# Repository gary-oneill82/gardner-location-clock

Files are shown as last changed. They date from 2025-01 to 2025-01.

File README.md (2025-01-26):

# The Gardner (Weasley) Family Clock

Happy Birthday Paul and welcome to your own version of the Weasley family clock!  The mechanism is mostly 3D printed and the STL files are available in the repository should anything break or wear out.

## First Start

When you first plug the clock in it will run a demonstration mode to move the hands to various locations before returning to home.  The Clock will present an Access Point with an SSID of "Location-Clock", I have given Laura the password.  Connect to the AP and connect to your own Wifi, the clock will now be available at http://weasley-clock.local, Laura has the Log in details for this also.

## Basic Controls

The Control software has been written in [ESPHome](https://esphome.io/) and provides a Web Server with [REST API](https://esphome.io/web-api/#api-rest).  Both hands are controlled by "Select" entities on the clock and the current state can be returned with a GET request to `http://weasley-clock.local/select/laura_location?detail=all` or `http://weasley-clock.local/select/paul_location?detail=all` this will return the following JSON Payload:
```
{
  "id":"select-laura_location",
  "name":"Laura Location",
  "icon":"",
  "entity_category":0,
  "value":"Home",
  "state":"Home",
  "option":["Home","Hogwarts","Work","Hogsmede","Quiddich","Holiday","Crieff Hydro","In Transit","Mortal Peril","Lost"],
  "sorting_weight":2,
  "sorting_group":"Controls"
}
```
To Control the hands simply send a POST request, for example `http://weasley-clock.local/select/laura_location/set?option=Hogwarts`

## Automation

If you want the clock to update locations automatically you will need to work out the best way to do this for the two of you but there are a few options:

1. We run our Smart house on [Home Assistant](https://www.home-assistant.io/) which integrates directly with ESPHome devices, has iOS and Android apps that can report location back to the server and can be programmed with automations, this is pretty much an all in one solution.
2. OwnTracks is open source and requires a phone app and server at home (can be a Rapberry Pi) as used in [this project](https://github.com/WhereslyClock/MyWhereslyClock), you then just have to work out the bridge to send the POST request to the Clock
3. Any other loction tracking service with an API should work as well so long as you write a middle-man programme to report to the clock where you each are!

## Calibration

While the hands are glued to the shafts there may still be some drift over time, if the hands stop consistently pointing to the correct location I have built in a Calibration option.  To access this go to [http://weasley-clock.local](http://weasley-clock.local) while connected to your home network and switch the "Access Calibration" switch (you will need to refresh the web page after changing the switch).  Once this is done you should see some additional options:



You now need to do the following:
1. Select the person + location that needs calibration from the top
2. Refresh the page to force the control location to update
3. Slowly move the control until the hand is in the correct location (you can click the slider and use the arrow keys on the keyboard to move one small step at a time)
4. Press the Save Calibration button for the corresponding hand - this will update the Location with the current hand position

## Administration

If needed you can upload an updated firmware for the clock by selecting "Allow OTA updates" and refreshing the page.  The Firmware files are in the Firmware section of the repository along with the ESPHome YAML file should you wish to make any changes yourself.  If needed you can reflash the firmware direct from a computer by unscewing the clock face and gently unplugging the USB extension cable to the control board.  You can then plug the ESP-32S board direct into the computer to be presented with a serial port, you will need to hold the small "BOOT" button on the board and press the "EN" button to enable the bootloader mode.  When putting things back together I would suggeest plugging into the breakout board to avoid the servos pulling current through the controller.

IMG_20250125_200230~2

## Hardware

> [!IMPORTANT]
> The Hands are superglued to the shafts so if you need to take the clock apart let me know and I'll talk you through it.

+ Controller: ESP-32S Dev board
+ Hand Servos: [Tower Pro MG90S](https://towerpro.com.tw/product/mg90s-3/)
+ Gears and hands: 3D printed in PLA+
+ Fasteners: M2 grub screws (0.9mm Hex bit) for Gears, M5 Screws for main body.

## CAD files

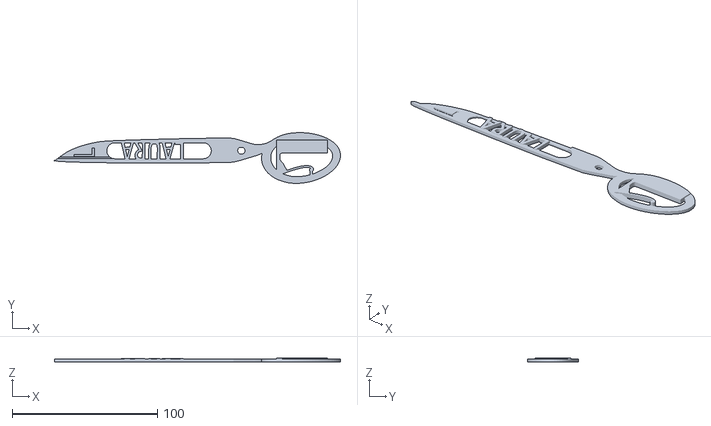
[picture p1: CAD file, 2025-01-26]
STL Files/Laura Hand.stl
197.0 x 35.0 x 2.85

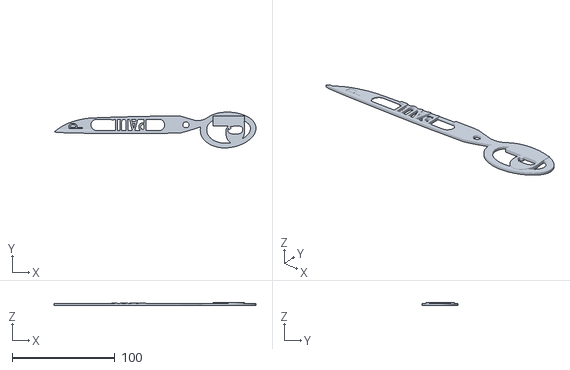
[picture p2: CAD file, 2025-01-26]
STL Files/Paul Hand.stl
197.0 x 35.0 x 2.54

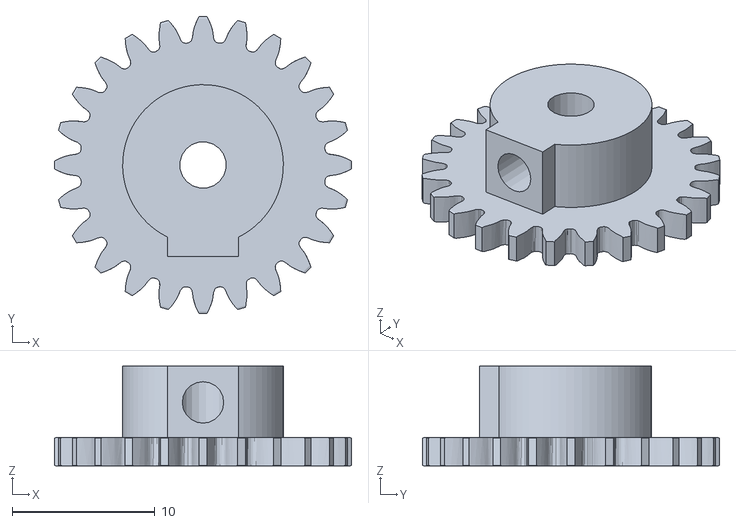
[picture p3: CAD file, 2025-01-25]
STL Files/3mm Center Gear.stl
20.8 x 20.8 x 7.00

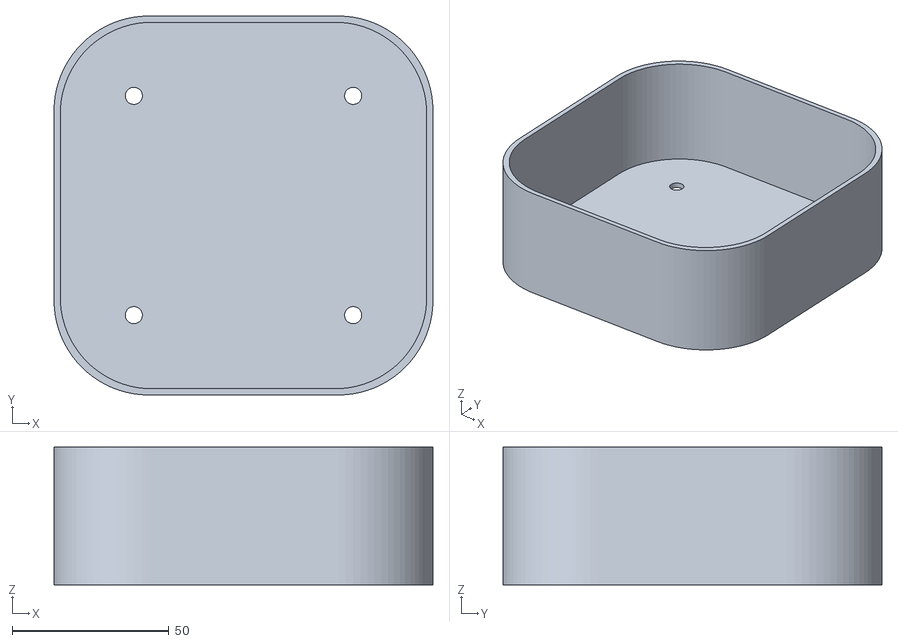
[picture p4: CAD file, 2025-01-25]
STL Files/Case Back.stl
121.0 x 121.0 x 44.0

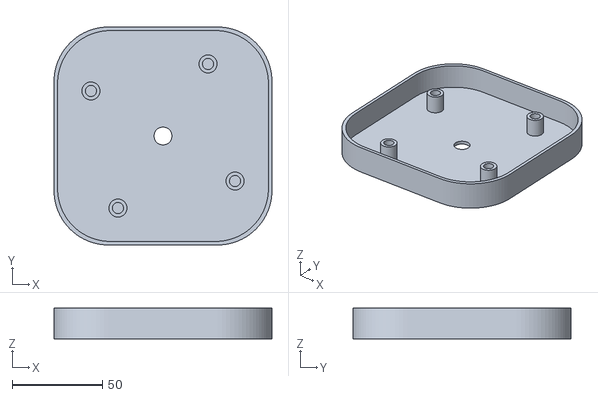
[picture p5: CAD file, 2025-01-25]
STL Files/Case Front.stl
121.0 x 121.0 x 17.0

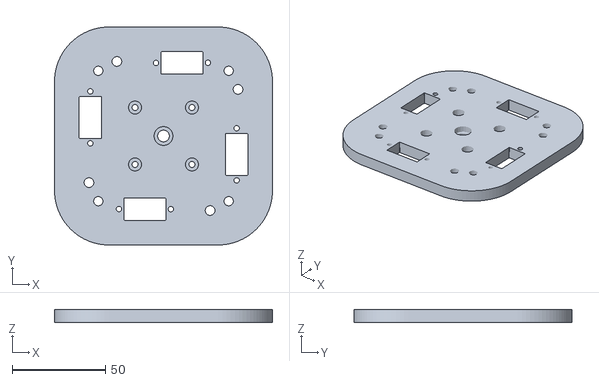
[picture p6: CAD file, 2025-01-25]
STL Files/Base Plate.stl
117.0 x 117.0 x 7.00

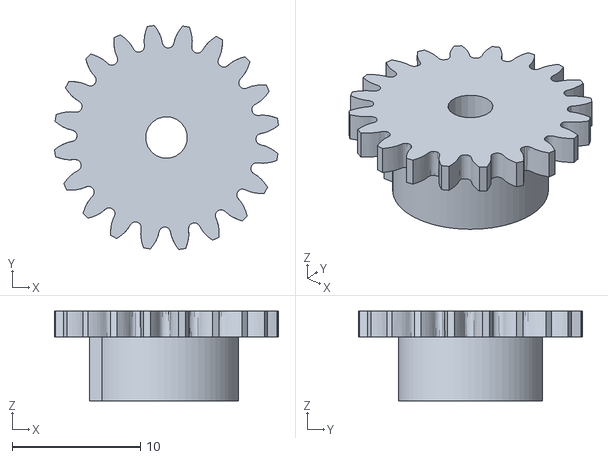
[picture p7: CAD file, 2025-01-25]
STL Files/Link Gear - Top.stl
17.5 x 17.5 x 7.00

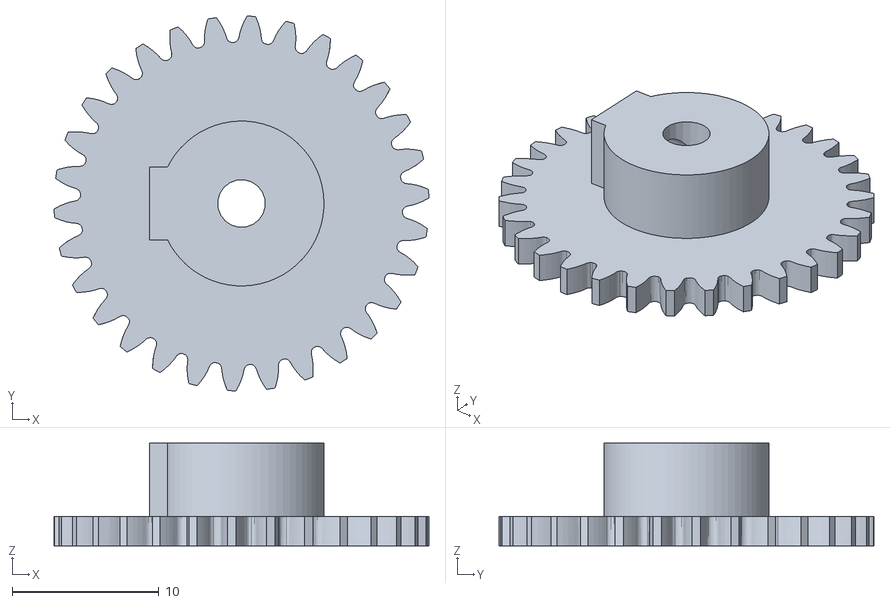
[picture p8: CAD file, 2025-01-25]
STL Files/Link Gear Bottom.stl
25.6 x 25.6 x 7.00

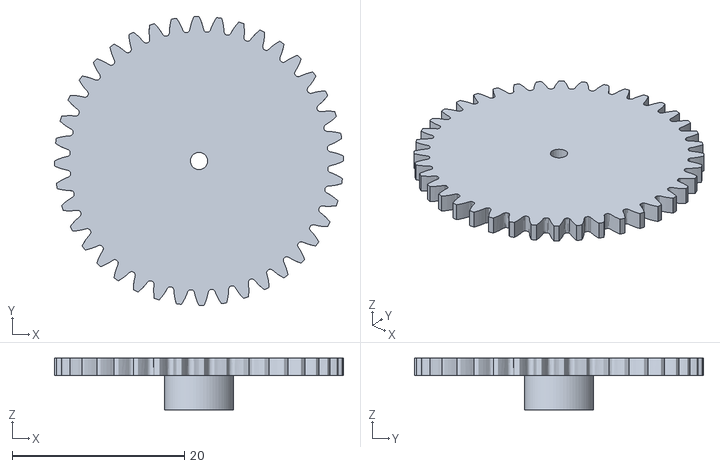
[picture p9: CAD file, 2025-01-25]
STL Files/Servo Gear.stl
33.6 x 33.6 x 6.00

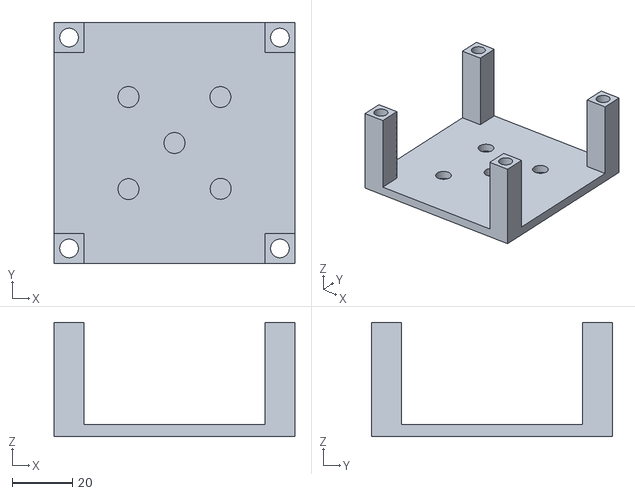
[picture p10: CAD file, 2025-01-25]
STL Files/Back Plate.stl
80.0 x 80.0 x 38.0

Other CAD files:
STL Files/5mm Center Gear.stl
STL Files/4mm Center Gear.stl
STL Files/6mm Center Gear.stl

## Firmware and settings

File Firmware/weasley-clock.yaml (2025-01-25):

esphome:
  name: weasley-clock
  friendly_name: Weasley Clock

esp32:
  board: esp32dev
  framework:
    type: arduino

# Enable logging
logger:

# Enable Home Assistant API
api:
  reboot_timeout: 0s

ota:
  - platform: esphome

wifi:

  # Enable fallback hotspot (captive portal) in case wifi connection fails
  ap:
    ssid: "Location-Clock"
    password: "PUT PASSWORD HERE"

captive_portal:

globals:
 #paul
  - id: paul_target
    type: int
    restore_value: True
    initial_value: '0'
  - id: paul_home
    type: int
    restore_value: True
    initial_value: '0'
  - id: paul_hogwarts
    type: int
    restore_value: True
    initial_value: '30'
  - id: paul_work
    type: int
    restore_value: True
    initial_value: '60'
  - id: paul_hogsmede
    type: int
    restore_value: True
    initial_value: '90'
  - id: paul_quiddich
    type: int
    restore_value: True
    initial_value: '120'
  - id: paul_holiday
    type: int
    restore_value: True
    initial_value: '-150'
  - id: paul_crieff_hydro
    type: int
    restore_value: True
    initial_value: '-120'
  - id: paul_in_transit
    type: int
    restore_value: True
    initial_value: '-90'
  - id: paul_mortal_peril
    type: int
    restore_value: True
    initial_value: '-60'
  - id: paul_lost
    type: int
    restore_value: True
    initial_value: '-30'
 #laura
  - id: laura_target
    type: int
    restore_value: True
    initial_value: '0'
  - id: laura_home
    type: int
    restore_value: True
    initial_value: '0'
  - id: laura_hogwarts
    type: int
    restore_value: True
    initial_value: '30'
  - id: laura_work
    type: int
    restore_value: True
    initial_value: '60'
  - id: laura_hogsmede
    type: int
    restore_value: True
    initial_value: '90'
  - id: laura_quiddich
    type: int
    restore_value: True
    initial_value: '120'
  - id: laura_holiday
    type: int
    restore_value: True
    initial_value: '-150'
  - id: laura_crieff_hydro
    type: int
    restore_value: True
    initial_value: '-120'
  - id: laura_in_transit
    type: int
    restore_value: True
    initial_value: '-90'
  - id: laura_mortal_peril
    type: int
    restore_value: True
    initial_value: '-60'
  - id: laura_lost
    type: int
    restore_value: True
    initial_value: '-30'

web_server:
  include_internal: false
  version: 3
  id: web_server_1
  ota: False
  log: False
  auth: 
    username: PUT USERNAME HERE
    password: PUT PASSWORD HERE
  sorting_groups:
    - id: clock_control
      name: "Controls"
      sorting_weight: -1
    - id: clock_config
      name: "Calibration"
      sorting_weight: 20
    - id: clock_admin
      name: "Administration"
      sorting_weight: 30

output:
  - platform: ledc
    id: servo_output_laura
    pin: GPIO32
    frequency: 50 Hz
  - platform: ledc
    id: servo_output_paul
    pin: GPIO33
    frequency: 50 Hz

servo:
  - id: laura_servo
    output: servo_output_laura
    min_level: 3%
    max_level: 12%
    auto_detach_time: 0.5s
  - id: paul_servo
    output: servo_output_paul
    min_level: 3%
    max_level: 12%
    auto_detach_time: 0.5s

switch:
  - platform: template
    name: "Access Calibration"
    optimistic: True
    restore_mode: ALWAYS_OFF
    web_server:
      sorting_group_id: clock_control
      sorting_weight: 3
    turn_on_action: 
      then:
        lambda: |-
          id(web_server_1).set_include_internal(true) ;
    turn_off_action: 
      then:
        lambda: |-  
          id(web_server_1).set_include_internal(false) ;
  - platform: template
    name: "Allow OTA updates"
    optimistic: True
    internal: True
    restore_mode: RESTORE_DEFAULT_OFF
    web_server:
      sorting_group_id: clock_admin
      sorting_weight: 90
    turn_on_action: 
      then:
        lambda: |-
          id(web_server_1).set_allow_ota(true) ;
    turn_off_action: 
      then:
        lambda: |-  
          id(web_server_1).set_allow_ota(false) ;

number:
  - platform: template
    name: Laura Control
    id: laura_control
    internal: True
    min_value: -180
    initial_value: 0
    max_value: 180
    step: 2
    optimistic: true
    restore_value: True
    web_server:
      sorting_group_id: clock_config
      sorting_weight: 30
    set_action:
      then:
        - servo.write:
            id: laura_servo
            level: !lambda 'return x /180;'
  - platform: template
    name: Paul Control
    id: paul_control
    internal: True
    min_value: -180
    initial_value: 0
    max_value: 180
    step: 2
    optimistic: true
    restore_value: True
    web_server:
      sorting_group_id: clock_config
      sorting_weight: 50
    set_action:
      then:
        - servo.write:
            id: paul_servo
            level: !lambda 'return x /180;'
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
